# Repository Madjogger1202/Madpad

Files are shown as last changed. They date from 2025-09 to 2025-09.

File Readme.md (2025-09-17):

# Madpad

> Custom macropad based on **RP2040** with display, audio feedback, and per-key RGB lighting.  
> Designed as a versatile input device for PC with extra features for interaction and visualization.  

---
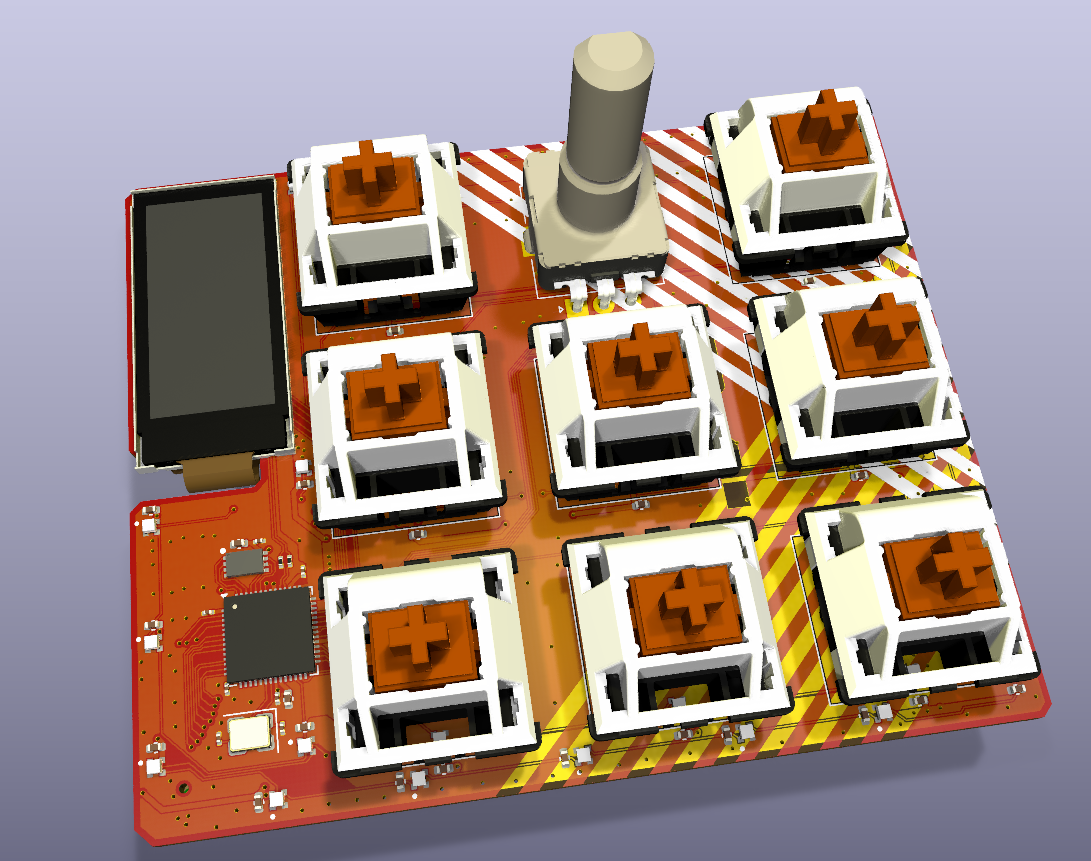
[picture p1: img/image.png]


## What’s on the board
- **RP2040 microcontroller**  
  - USB device (HID, MIDI, or custom protocols)  
- **IPS display (0.96")**  
  - Controller: **ST7735**  
  - For status output, macro layers, menus, or visual effects  
- **Microphone**: INMP441ACEZ-R7 (I²S interface)  
- **Piezo buzzer** with transistor driver for sound feedback  
- **Rotary encoder** with integrated push button  
- **8 mechanical keys** (macro switches)  
- **RGB lighting**:  
  - 1× WS2812 (1×1 mm) LED per key  
  - Additional WS2812 LEDs distributed across the board for **ambient light effects**  

---

## Connectivity
- **USB Type-C** for both power and PC connection  
- Enumerates as **USB HID keyboard/macropad** (firmware-dependent)  
- Can be extended to **MIDI control surface** or custom USB interfaces  

---

## Use Cases
- Macro pad for productivity (shortcuts, hotkeys, macros)  
- Custom controller for audio/video editing software  
- Mini MIDI controller for music applications  
- Experiment platform for RGB effects + input devices  

---

## Notes
- LED layout allows both **per-key lighting** and **global light animations**.  
- Buzzer and microphone make the board suitable for **interactive feedback** or audio experiments.  
- Rotary encoder + display add flexibility for menus, layers, or volume control.  

---

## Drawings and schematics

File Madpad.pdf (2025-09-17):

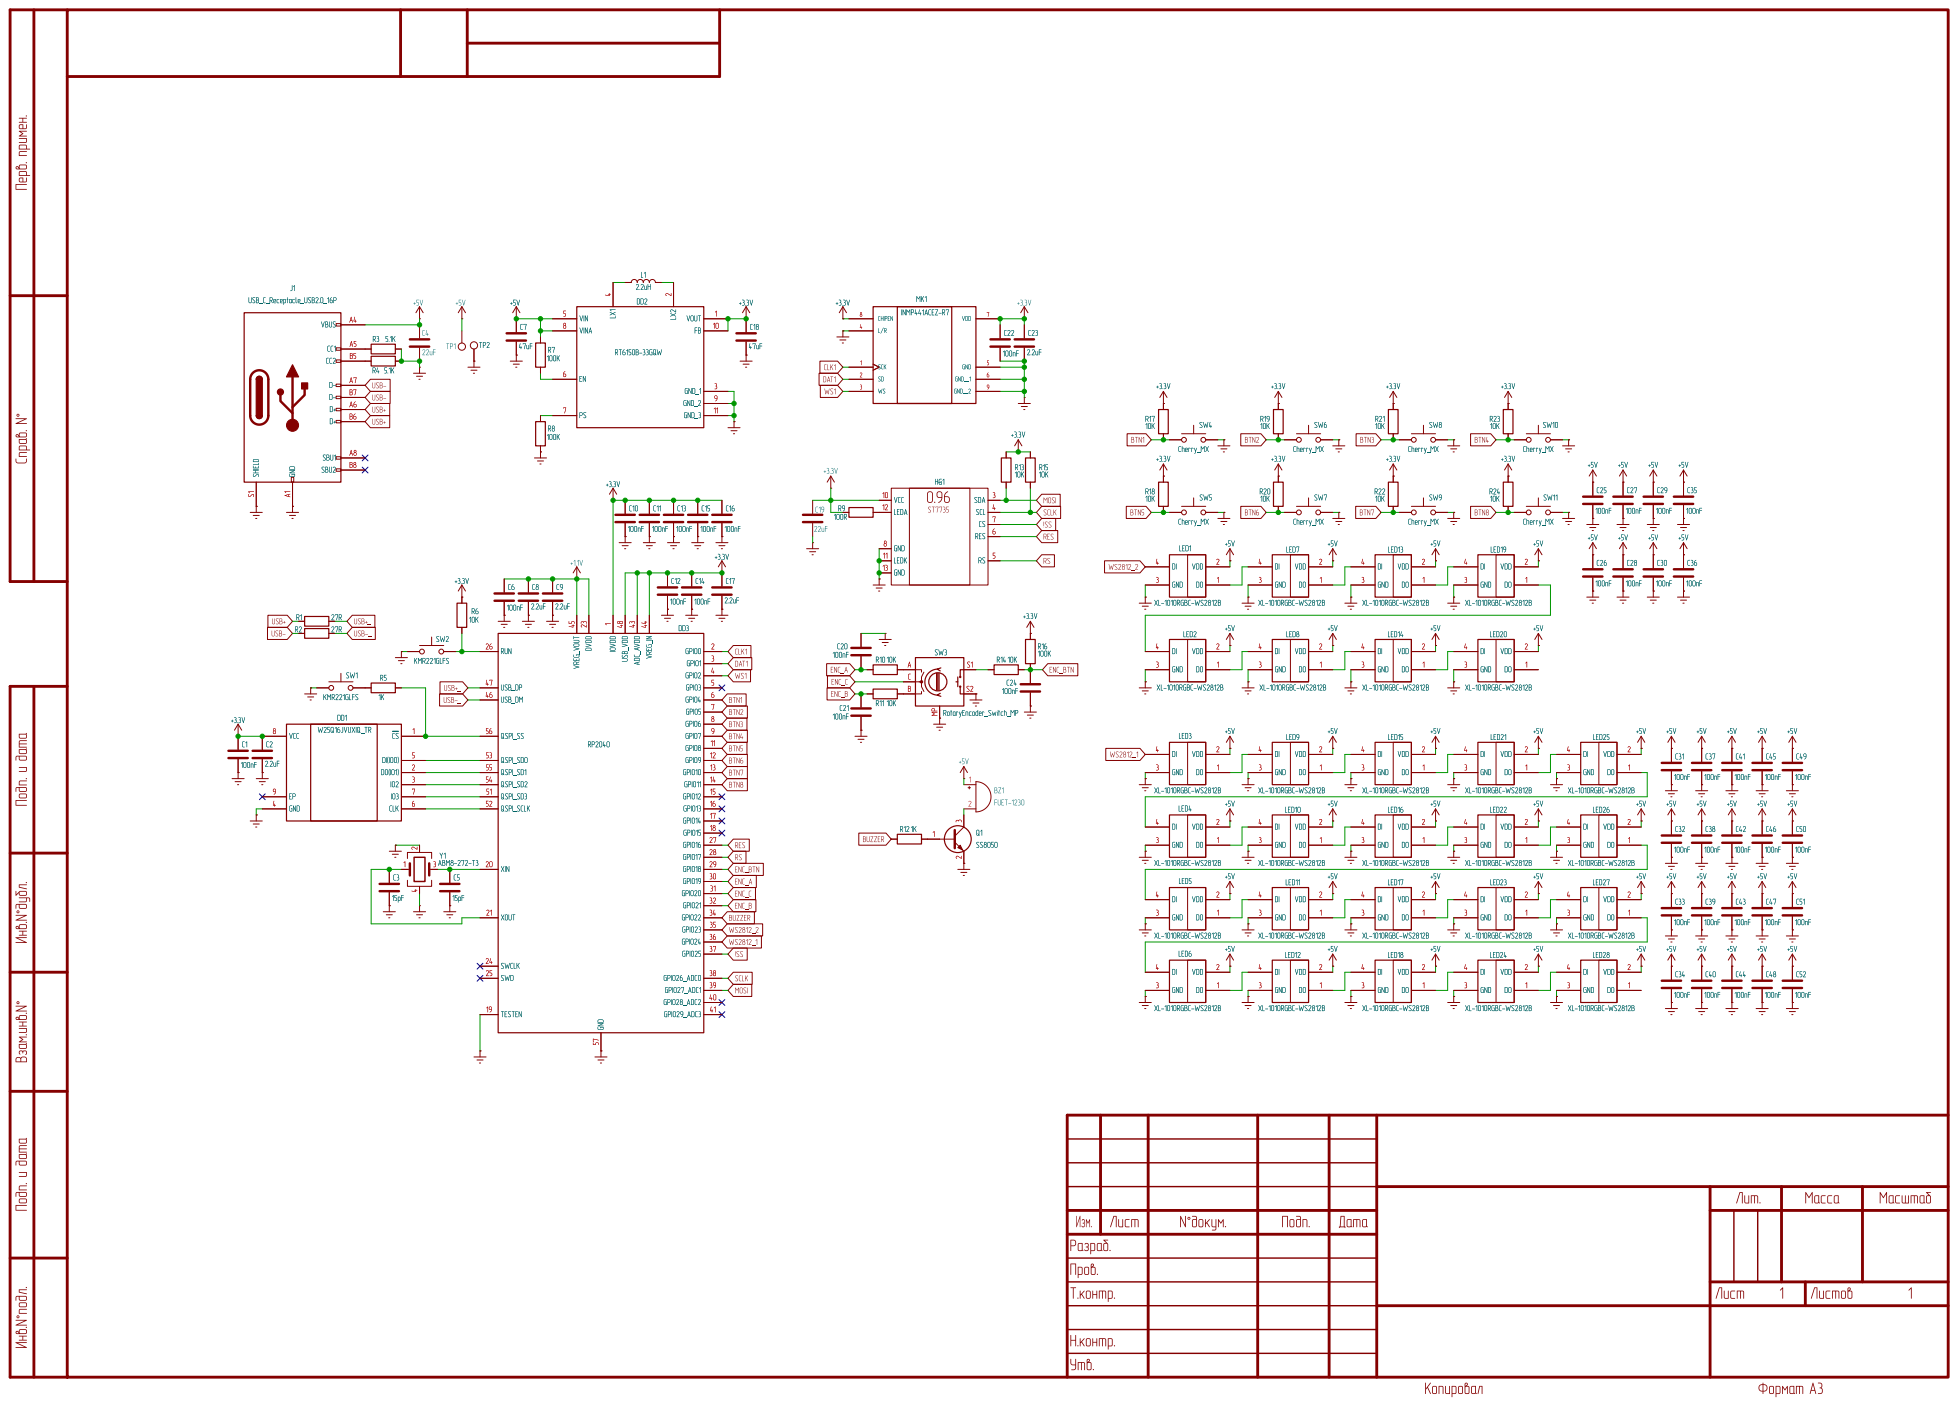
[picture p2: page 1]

þÿ@>2.
þÿ".:>=B@.

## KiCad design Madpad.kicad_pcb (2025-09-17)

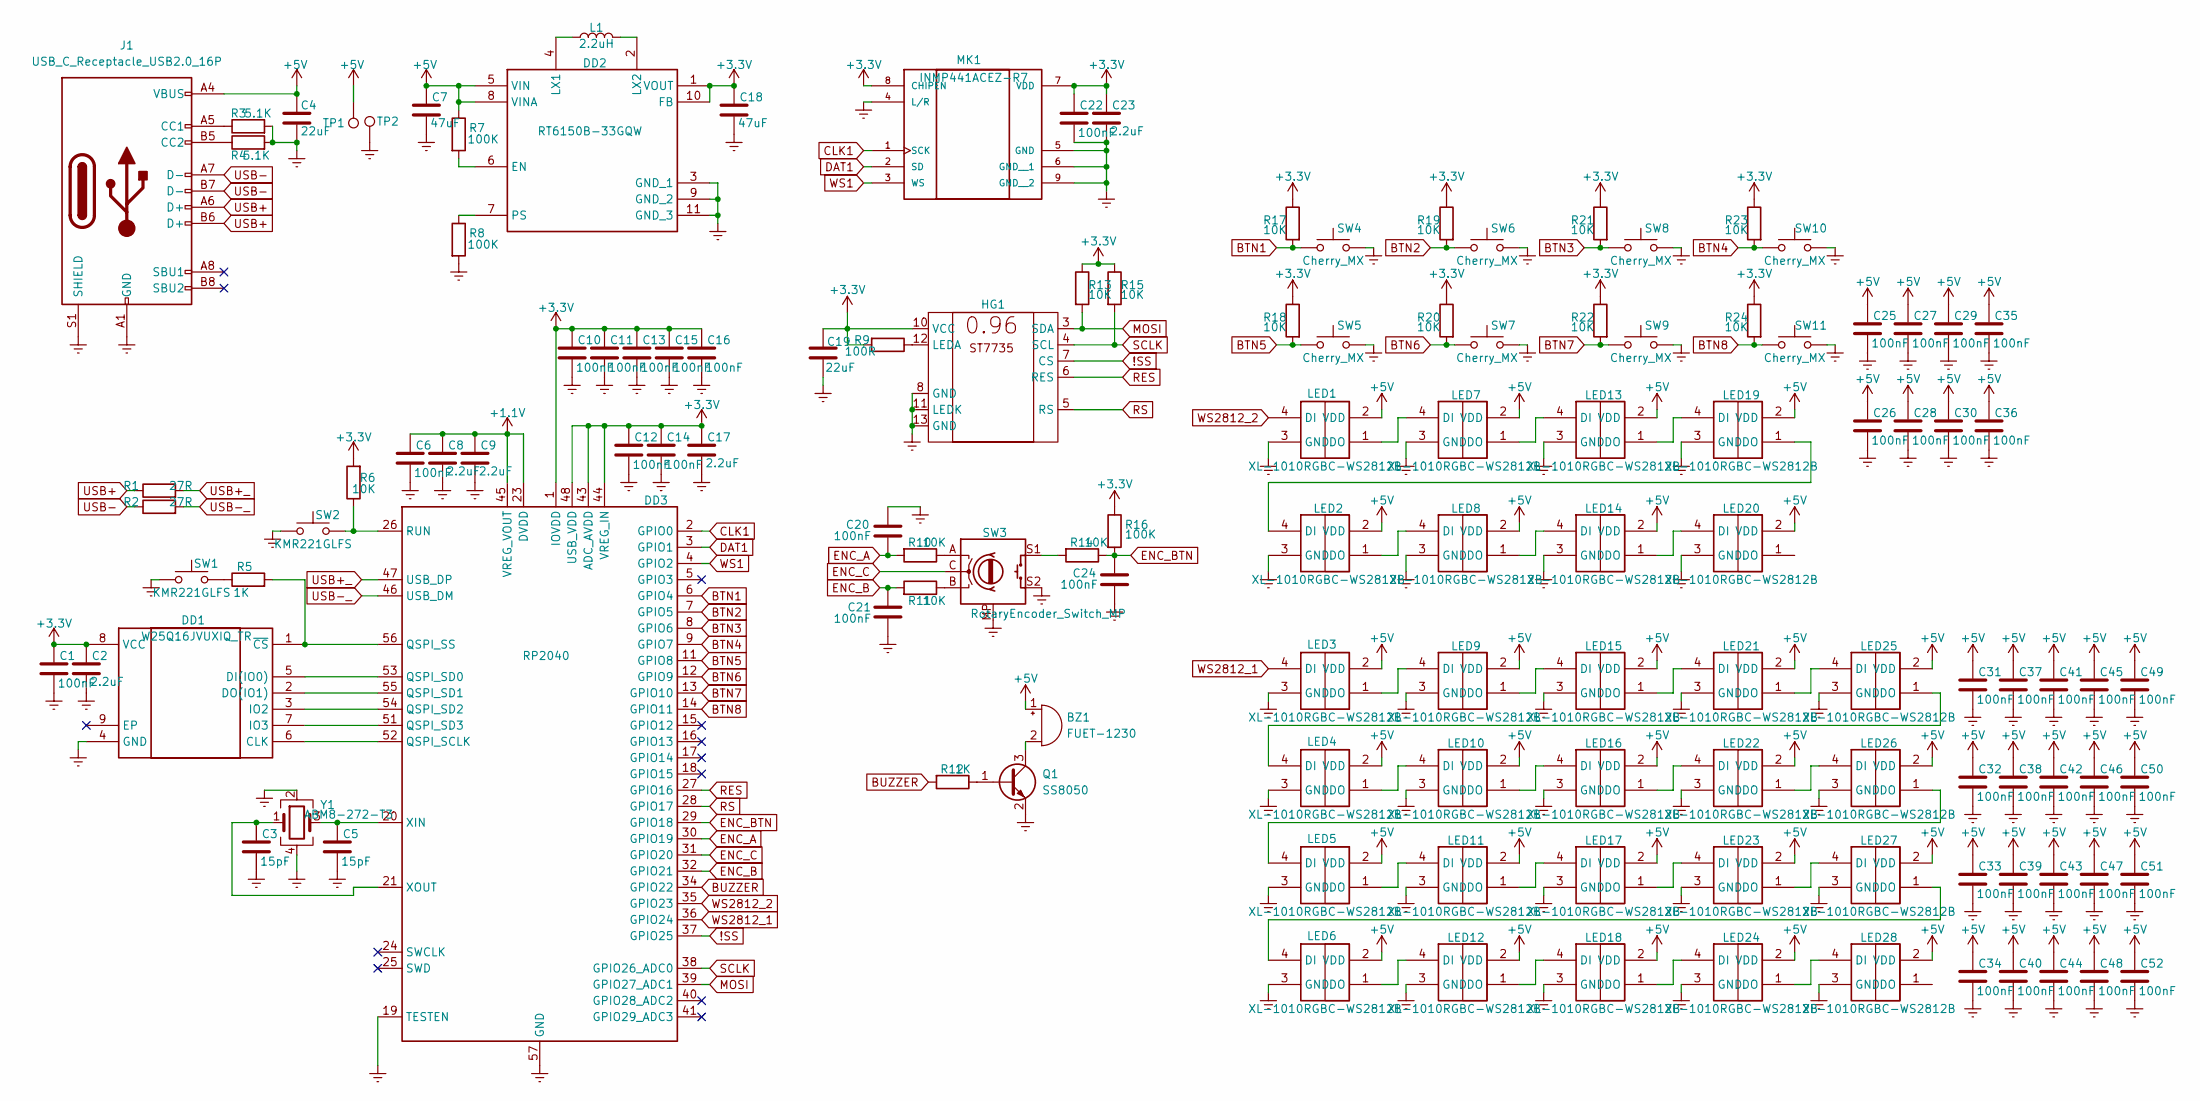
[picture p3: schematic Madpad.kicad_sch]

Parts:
BZ1: FUET-1230; Buzzer_Murata_PKLCS1212E
C1, C6, C10, C11, C12, C13, C14, C15, C16, C22: 100nF; C_0201_0603Metric
C2, C8, C9, C17, C23: 2.2uF; C_0402_1005Metric
C3, C5: 15pF; C_0201_0603Metric
C4, C19: 22uF; C_0402_1005Metric
C7, C18: 47uF; C_0805_2012Metric
C20, C21, C24, C25, C26, C27, C28, C29, C30, C31, C32, C33, C34, C35, C36, C37, C38, C39, C40, C41, C42, C43, C44, C45, C46, C47, C48, C49, C50, C51, C52: 100nF; C_0402_1005Metric
DD1: W25Q16JVUXIQ_TR; W25Q16JVUXIQ; Manufacturer_Part_Number W25Q16JVUXIQ TR; Mouser Part Number 454-W25Q16JVUXIQTR
DD2: RT6150B-33GQW; Manufacturer_Part_Number RT6150B-33GQW; Mouser Part Number 835-RT6150B-33GQW
DD3: RP2040; QFN-56-1EP_7x7mm_P0.4mm_EP3.2x3.2mm
HG1: ST7735 0.96
J1: USB_C_Receptacle_USB2.0_16P; USB_C_Receptacle_GCT_USB4105-xx-A_16P_TopMnt_Horizontal
L1: 2.2uH; L_1008_2520Metric
LED1, LED2, LED3, LED4, LED5, LED6, LED7, LED8, LED9, LED10, LED11, LED12, LED13, LED14, LED15, LED16, LED17, LED18, LED19, LED20, LED21, LED22, LED23, LED24, LED25, LED26, LED27, LED28: XL-1010RGBC-WS2812B; XL1010RGBCWS2812B; Manufacturer_Part_Number XL-1010RGBC-WS2812B
MK1: INMP441ACEZ-R7; INMP441; PARTREV 1.1
Q1: SS8050; SOT-23
R1, R2: 27R; R_0201_0603Metric
R3, R4: 5.1K; R_0402_1005Metric
R5, R12: 1K; R_0402_1005Metric
R6, R10, R11, R13, R14, R15, R17, R18, R19, R20, R21, R22, R23, R24: 10K; R_0402_1005Metric
R7, R8, R16: 100K; R_0402_1005Metric
R9: 100R; R_0402_1005Metric
SW1, SW2: KMR221GLFS; SW_SPST_PTS810
SW3: RotaryEncoder_Switch_MP; RotaryEncoder_Alps_EC11E-Switch_Vertical_H20mm
SW4, SW5, SW6, SW7, SW8, SW9, SW10, SW11: Cherry_MX; SW_Cherry_MX_PCB_1.00u
TP1, TP2: TestPoint_Pad_1.5x1.5mm
Y1: ABM8-272-T3; Crystal_SMD_3225-4Pin_3.2x2.5mm

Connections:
!SS: DD3.37 (GPIO25), HG1.7 (CS)
+1.1V: C6.1, C8.1, C9.1, DD3.23 (DVDD), DD3.45 (VREG_VOUT), DD3.50 (DVDD)
+3.3V: C1.1, C2.1, C10.1, C11.1, C12.1, C13.1, C14.1, C15.1, C16.1, C17.1, C18.1, C19.1, C22.1, C23.1, DD1.8 (VCC), DD2.1 (VOUT), DD2.10 (FB), DD3.1 (IOVDD), DD3.10 (IOVDD), DD3.22 (IOVDD), DD3.33 (IOVDD), DD3.42 (IOVDD), DD3.43 (ADC_AVDD), DD3.44 (VREG_IN), DD3.48 (USB_VDD), DD3.49 (IOVDD), HG1.10 (VCC), MK1.7 (VDD), MK1.8 (CHIPEN), R6.2, R9.2, R13.1, R15.1, R16.1, R17.1, R18.1, R19.1, R20.1, R21.1, R22.1, R23.1, R24.1
+5V: BZ1.1 (+), C4.1, C7.1, C25.1, C26.1, C27.1, C28.1, C29.1, C30.1, C31.1, C32.1, C33.1, C34.1, C35.1, C36.1, C37.1, C38.1, C39.1, C40.1, C41.1, C42.1, C43.1, C44.1, C45.1, C46.1, C47.1, C48.1, C49.1, C50.1, C51.1, C52.1, DD2.5 (VIN), DD2.8 (VINA), J1.A4 (VBUS), J1.A9 (VBUS), J1.B4 (VBUS), J1.B9 (VBUS), LED1.2 (VDD), LED2.2 (VDD), LED3.2 (VDD), LED4.2 (VDD), LED5.2 (VDD), LED6.2 (VDD), LED7.2 (VDD), LED8.2 (VDD), LED9.2 (VDD), LED10.2 (VDD), LED11.2 (VDD), LED12.2 (VDD), LED13.2 (VDD), LED14.2 (VDD), LED15.2 (VDD), LED16.2 (VDD), LED17.2 (VDD), LED18.2 (VDD), LED19.2 (VDD), LED20.2 (VDD), LED21.2 (VDD), LED22.2 (VDD), LED23.2 (VDD), LED24.2 (VDD), LED25.2 (VDD), LED26.2 (VDD), LED27.2 (VDD), LED28.2 (VDD), R7.1, TP1.1
BTN1: DD3.6 (GPIO4), R17.2, SW4.2
BTN2: DD3.7 (GPIO5), R19.2, SW6.2
BTN3: DD3.8 (GPIO6), R21.2, SW8.2
BTN4: DD3.9 (GPIO7), R23.2, SW10.2
BTN5: DD3.11 (GPIO8), R18.2, SW5.2
BTN6: DD3.12 (GPIO9), R20.2, SW7.2
BTN7: DD3.13 (GPIO10), R22.2, SW9.2
BTN8: DD3.14 (GPIO11), R24.2, SW11.2
BUZZER: DD3.34 (GPIO22), R12.2
CLK1: DD3.2 (GPIO0), MK1.1 (SCK)
DAT1: DD3.3 (GPIO1), MK1.2 (SD)
ENC_A: C20.2, DD3.30 (GPIO19), R10.2
ENC_B: C21.1, DD3.32 (GPIO21), R11.2
ENC_BTN: C24.1, DD3.29 (GPIO18), R14.1, R16.2
ENC_C: DD3.31 (GPIO20), SW3.C
Earth: C1.2, C2.2, C3.2, C4.2, C5.2, C6.2, C7.2, C8.2, C9.2, C10.2, C11.2, C12.2, C13.2, C14.2, C15.2, C16.2, C17.2, C18.2, C19.2, C20.1, C21.2, C22.2, C23.2, C24.2, C25.2, C26.2, C27.2, C28.2, C29.2, C30.2, C31.2, C32.2, C33.2, C34.2, C35.2, C36.2, C37.2, C38.2, C39.2, C40.2, C41.2, C42.2, C43.2, C44.2, C45.2, C46.2, C47.2, C48.2, C49.2, C50.2, C51.2, C52.2, DD1.4 (GND), DD2.3 (GND_1), DD2.9 (GND_2), DD2.11 (GND_3), DD3.19 (TESTEN), DD3.57 (GND), HG1.8 (GND), HG1.11 (LEDK), HG1.13 (GND), J1.A1 (GND), J1.A12 (GND), J1.B1 (GND), J1.B12 (GND), J1.S1 (SHIELD), LED1.3 (GND), LED2.3 (GND), LED3.3 (GND), LED4.3 (GND), LED5.3 (GND), LED6.3 (GND), LED7.3 (GND), LED8.3 (GND), LED9.3 (GND), LED10.3 (GND), LED11.3 (GND), LED12.3 (GND), LED13.3 (GND), LED14.3 (GND), LED15.3 (GND), LED16.3 (GND), LED17.3 (GND), LED18.3 (GND), LED19.3 (GND), LED20.3 (GND), LED21.3 (GND), LED22.3 (GND), LED23.3 (GND), LED24.3 (GND), LED25.3 (GND), LED26.3 (GND), LED27.3 (GND), LED28.3 (GND), MK1.4 (L/R), MK1.5 (GND), MK1.6 (GND__1), MK1.9 (GND__2), Q1.2 (E), R3.2, R4.2, R8.2, SW1.1, SW2.1, SW3.MP, SW3.S2, SW4.1, SW5.1, SW6.1, SW7.1, SW8.1, SW9.1, SW10.1, SW11.1, TP2.1, Y1.2, Y1.4
MOSI: DD3.39 (GPIO27_ADC1), HG1.3 (SDA), R13.2
unnamed: BZ1.2 (-), Q1.3 (C)
unnamed: DD1.6 (CLK), DD3.52 (QSPI_SCLK)
unnamed: DD1.5 (DI(IO0)), DD3.53 (QSPI_SD0)
unnamed: DD1.2 (DO(IO1)), DD3.55 (QSPI_SD1)
unnamed: DD1.3 (IO2), DD3.54 (QSPI_SD2)
unnamed: DD1.7 (IO3), DD3.51 (QSPI_SD3)
unnamed: DD1.1 (~CS), DD3.56 (QSPI_SS), R5.2
unnamed: DD2.6 (EN), R7.2
unnamed: DD2.4 (LX1), L1.1
unnamed: DD2.2 (LX2), L1.2
unnamed: DD2.7 (PS), R8.1
unnamed: DD3.26 (RUN), R6.1, SW2.2
unnamed: C5.1, DD3.20 (XIN), Y1.3
unnamed: C3.1, DD3.21 (XOUT), Y1.1
unnamed: HG1.12 (LEDA), R9.1
unnamed: J1.A5 (CC1), R3.1
unnamed: J1.B5 (CC2), R4.1
unnamed: LED1.1 (DO), LED7.4 (DI)
unnamed: LED2.1 (DO), LED8.4 (DI)
unnamed: LED3.1 (DO), LED9.4 (DI)
unnamed: LED4.1 (DO), LED10.4 (DI)
unnamed: LED10.1 (DO), LED16.4 (DI)
unnamed: LED5.1 (DO), LED11.4 (DI)
unnamed: LED11.1 (DO), LED17.4 (DI)
unnamed: LED6.1 (DO), LED12.4 (DI)
unnamed: LED12.1 (DO), LED18.4 (DI)
unnamed: LED7.1 (DO), LED13.4 (DI)
unnamed: LED13.1 (DO), LED19.4 (DI)
unnamed: LED8.1 (DO), LED14.4 (DI)
unnamed: LED14.1 (DO), LED20.4 (DI)
unnamed: LED9.1 (DO), LED15.4 (DI)
unnamed: LED15.1 (DO), LED21.4 (DI)
unnamed: LED16.1 (DO), LED22.4 (DI)
unnamed: LED17.1 (DO), LED23.4 (DI)
unnamed: LED18.1 (DO), LED24.4 (DI)
unnamed: LED2.4 (DI), LED19.1 (DO)
unnamed: LED21.1 (DO), LED25.4 (DI)
unnamed: LED22.1 (DO), LED26.4 (DI)
unnamed: LED23.1 (DO), LED27.4 (DI)
unnamed: LED24.1 (DO), LED28.4 (DI)
unnamed: LED4.4 (DI), LED25.1 (DO)
unnamed: LED5.4 (DI), LED26.1 (DO)
unnamed: LED6.4 (DI), LED27.1 (DO)
unnamed: Q1.1 (B), R12.1
unnamed: R5.1, SW1.2
unnamed: R10.1, SW3.A
unnamed: R11.1, SW3.B
unnamed: R14.2, SW3.S1
RES: DD3.27 (GPIO16), HG1.6 (RES)
RS: DD3.28 (GPIO17), HG1.5 (RS)
SCLK: DD3.38 (GPIO26_ADC0), HG1.4 (SCL), R15.2
USB+: J1.A6 (D+), J1.B6 (D+), R1.1
USB+_: DD3.47 (USB_DP), R1.2
USB-: J1.A7 (D-), J1.B7 (D-), R2.1
USB-_: DD3.46 (USB_DM), R2.2
WS1: DD3.4 (GPIO2), MK1.3 (WS)
WS2812_1: DD3.36 (GPIO24), LED3.4 (DI)
WS2812_2: DD3.35 (GPIO23), LED1.4 (DI)

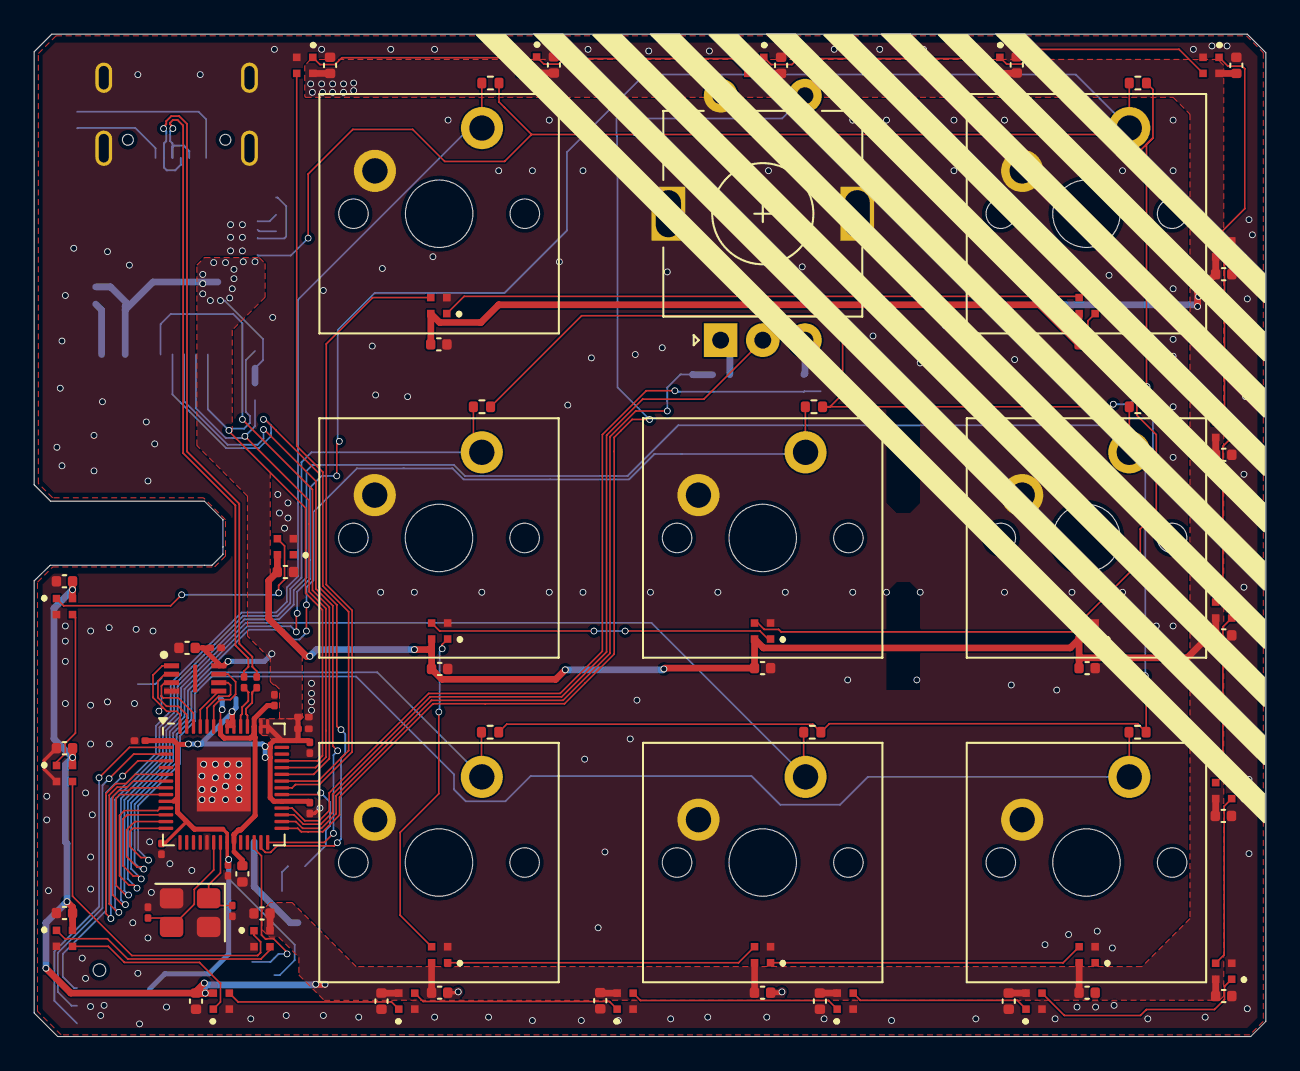
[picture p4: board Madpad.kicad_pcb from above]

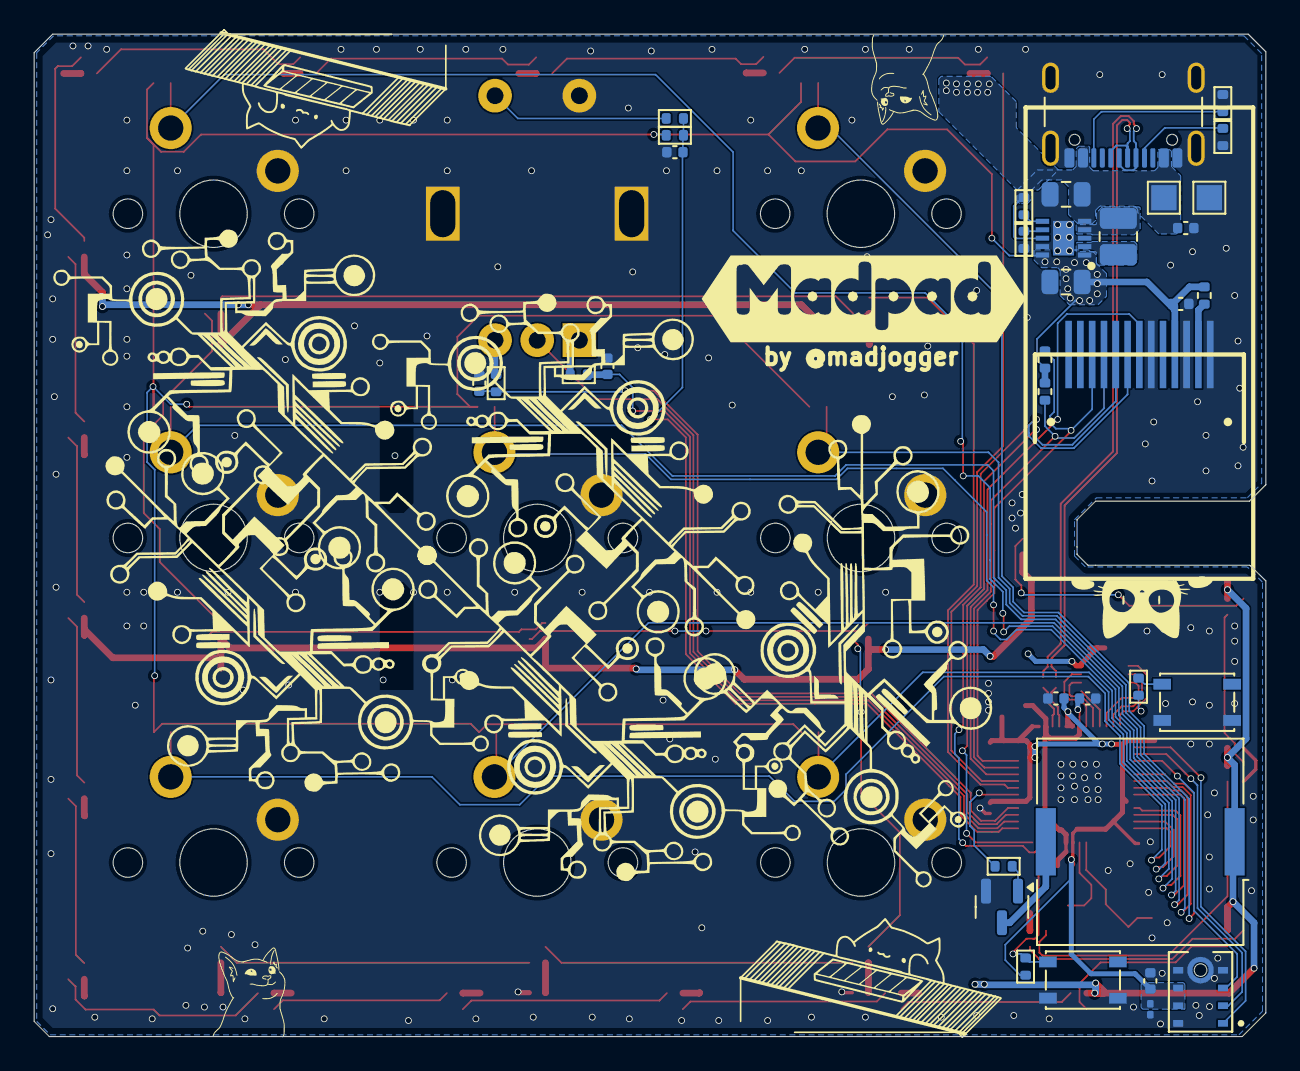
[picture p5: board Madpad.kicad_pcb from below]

Board: 2 copper layers, 73.0 x 59.4 mm, 128 parts (37 on the bottom side), 79 nets.

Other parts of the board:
kibuzzard-68CB22F7: G***; kibuzzard-68CB22F7
